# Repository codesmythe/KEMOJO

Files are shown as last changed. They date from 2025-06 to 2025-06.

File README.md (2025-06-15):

# KEMOJO (Keyboard / Mouse / Joystick)

KEMOJO

This board provides PS/2 keyboard, PS/2 mouse and Atari or MSX (single
button only) joystick support for an RCBus system. It uses the 40-pin
RCBus interface. 

The keyboard, mouse and joystick inputs are read by an ATmega 328P
microcontoller. (This is the same MCU that is in the Arduino UNO.) The
ATmega implements the [Atari ST IKBD
protcol](https://archive.org/details/Intelligent_Keyboard_ikbd_Protocol_Feb_26_1985/)
and communicates that protocol serially to an RCBus system via a
16C550 UART.

## Table of Contents
* [Hardware Documentation](#hardware-documentation)
  * [Schematic](#schematic)
  * [Connectors](#connectors)
  * [Jumpers](#jumpers)
  * [Bill of Materials](#bill-of-materials)
* [Firmware Documentation](#firmware-documentation)
* [Acknowledgements](#acknowledgements)

## Hardware Documentation

### Schematic

The board was created using [Kicad](https://www.kicad.org) version 8.0.

Click the image to download a PDF version of the schematic.

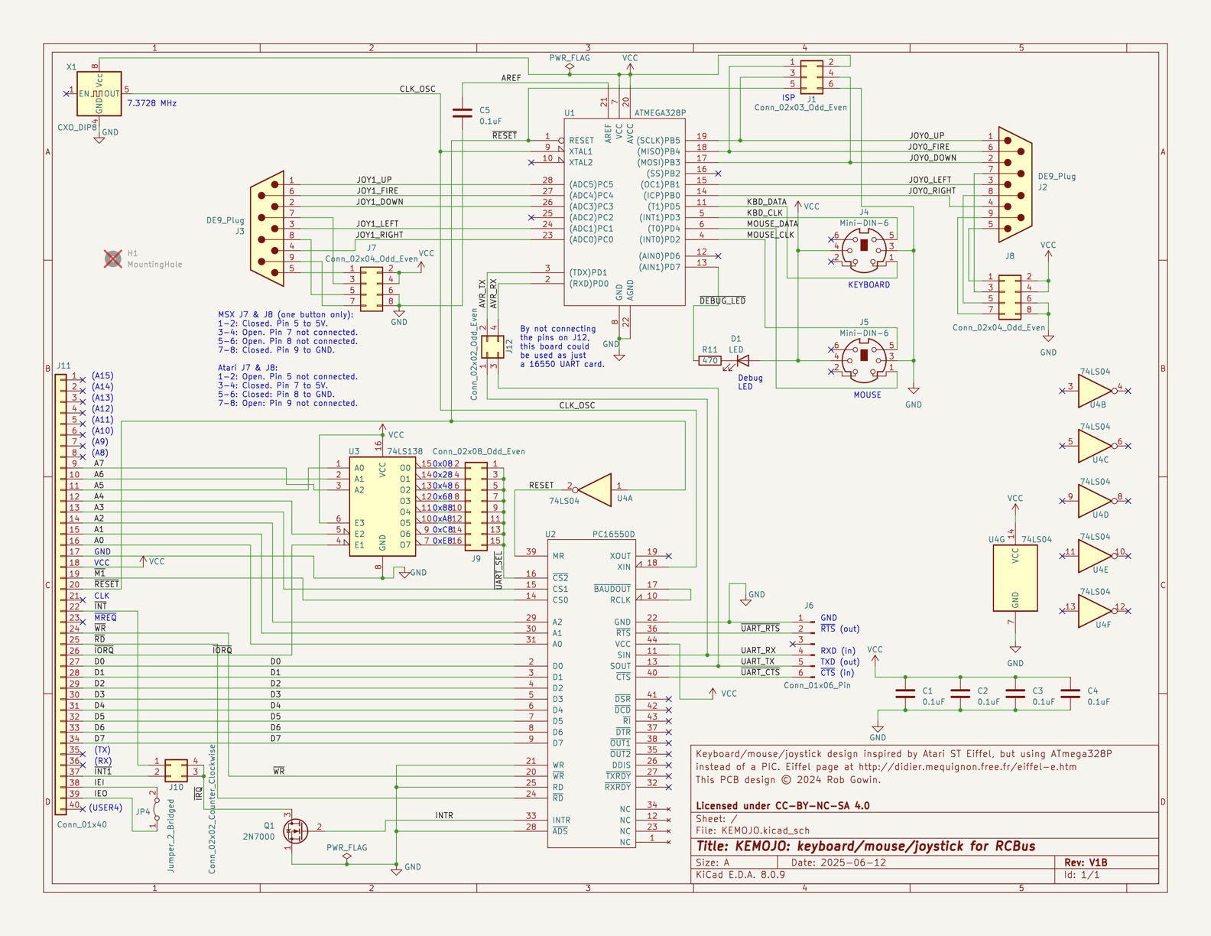
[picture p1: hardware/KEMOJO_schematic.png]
Schematic


### Connectors

| Reference | Description |
| --- | --- |
| J1 | In-system Programming (ISP) port for programming the ATmega328P firmware. |
| J2 | Atari or MSX Joystick 0, Male DE9 D-Sub. See J7 jumper settings below. |
| J3 | Atari or MSX Joystick 1, Male DE9 D-Sub. See J8 jumper settings below. |
| J4 | PS/2 6-pin Mini DIN connector for PS/2 keyboard. |
| J5 | PS/2 6-pin Mini DIN connector for PS/2 mouse. |
| J6 | [FTDI Friend](https://www.adafruit.com/product/284) connection to 16C550 UART. For debug purposes or UART-only operation. |

### Jumpers

| Reference | Description | Comment |
| --- | --- | --- |
| J7, J8 | Atari or MSX operation for Joystick 1/0 | The J7 and J8 jumper blocks configue Joystick 1 and Joystick 0, respectively, for either Atari or MSX joystick operation. In MSX mode, only one fire button is supported. To configure a jumper block for Atari mode, close the top and bottom jumpers, and leave the middle two open. For MSX mode, close the middle two jumpers and leave the top and bottom jumpers open. |
| J9 | I/O Address decode | The J9 jumper block controls where in the Z80 I/O space the KEMOJO board will appear. The TL16C550 UART that communicates with the ATmega328 requires eight I/O addresses, and can be configured to appear at I/O addresses 0x08-0x0F, 0x28-0x2F, 0x48-0x4F, 0x68-0x6F, 0x88-0x8F, 0xA8-0xAF, 0xC8-0xCF or 0xE8-0xEF. |
| J10 | Interrupt connection to RCBus | The board can generate a single interrupt from the TL16C550 UART. Jumper the top two pins of J10 to use the /INT RCBus signal (pin 22) or the bottom two pins to use the RCBus USER1/INT1 signal (pin 37). |
| JP4 | IEx bypass | When the JP4 jumper is closed, the RCBus-Z80 IEI signal (pin 37) is connected directly to the IEO signal (pin 38). When closed, the board is disconnected from RCBus pins 37 and 38. The KEMOJO board does not use IEI or IEO. This jumper is provided to propagate the IEI/IEO daisy chained if required by the system. |

### Bill of Materials

[Text file parts list](hardware/KEMOJO_mouser.txt) for pasting into the [Mouser BOM tool](https://www.mouser.com/Bom/CopyPaste) (login required).

Check out the [interactive BOM](https://htmlpreview.github.io/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)
for the board.

To obtain a KEMOJO PCB, download these [Gerbers](https://raw.githubusercontent.com/codesmythe/KEMOJO/refs/heads/main/hardware/KEMOJO_V1B.zip) for use at your preferred PCB manufacturer. I use JLCPCB. 

| Component Type | Reference | Qty | Description | Part |
| --- | --- | --- | --- | --- |
| Capacitor | C1,C2,C3,C4,C5 | 5 | 0.1 uF, MLCC, 5 mm Pitch | Mouser [594-K104K15X7RF5WH5](https://www.mouser.com/ProductDetail/594-K104K15X7RF5WH5) |
| Diode | D1 | 1 | 3 mm, yellow LED indicator | Mouser [859-LTL-4251N](https://www.mouser.com/ProductDetail/859-LTL-4251N) |
| Connnector | J1 | 1 | 2x3 straight pin header | Mouser [200-TSW10307TD](https://www.mouser.com/ProductDetail/200-TSW10307TD) |
| Connector | J2,J3 | 2 | D-Sub DE9 Male, right angle, PCB mount | Mouser [523-L7SDE9PA4CH4RC39](https://www.mouser.com/ProductDetail/523-L7SDE9PA4CH4RC39) |
| Connector | J4,J5 | 2 | Circular 6-pin Mini Din Connector for PS/2 | Mouser [490-MD-40SM](https://www.mouser.com/ProductDetail/490-MD-40SM) |
| Connector | J6 | 1 | 1x6 right angle pin header | Mouser [737-PH1RB-06-UA](https://www.mouser.com/ProductDetail/737-PH1RB-06-UA) |
| Jumper Block | J7,J8 | 2 | 2x4 straight pin header | Mouser [200-TSW10407TD](https://www.mouser.com/ProductDetail/200-TSW10407TD) |
| Jumper Block | J9 | 1 | 2x8 straight pin header | Mouser [200-TSW10807TD](https://www.mouser.com/ProductDetail/200-TSW10807TD) |
| Jumper Block | J10 | 1 | 2x2 straight pin header | Mouser [200-TSW10207TD](https://www.mouser.com/ProductDetail/200-TSW10207TD) |
| Connector | J11 | 1 | 1x40 right angle pin header | Mouser [710-61304011021](https://www.mouser.com/ProductDetail/710-61304011021) |
| Jumper Block | J12 | 1 | 2x2 straight pin header | Mouser [200-TSW10207TD](https://www.mouser.com/ProductDetail/200-TSW10207TD) |
| Jumper | JP4 | 1 | 1x2 straight pin header | Mouser [200-TSW10207TS](https://www.mouser.com/ProductDetail/200-TSW10207TS) |
| Transistor | Q1 | 1 | 2N7000  MOSFET in TO92 | Mouser [512-2N7000](https://www.mouser.com/ProductDetail/512-2N7000) |
| Resistor | R11 | 1 | 470 ohm, axial, 1% tolerance, 1/4 W | Mouser [603-MFR-25FTF52-470R](https://www.mouser.com/ProductDetail/603-MFR-25FTF52-470R) |
| Integrated Circuit | U1 | 1 | ATmega328P MCU in 28-pin DIP | Mouser [556-ATMEGA328P-PU](https://www.mouser.com/ProductDetail/556-ATMEGA328P-PU) |
| Integrated Circuit | U2 | 1 | TL16C550 UART in 44-pin PLCC | Mouser [595-TL16C550CFNR](https://www.mouser.com/ProductDetail/595-TL16C550CFNR) |
| Integrated Circuit | U3 | 1 | 74LS138 in 16-pin DIP | Mouser [595-SN74LS138NE4](https://www.mouser.com/ProductDetail/595-SN74LS138NE4) |
| Integrated Circuit | U4 | 1 | 74LS04 in 14-pin DIP | Mouser [595-SN74LS04NE4](https://www.mouser.com/ProductDetail/595-SN74LS04NE4) |
| Oscillator | X1 | 1 | 7.3278 MHz can oscillator in 8-pin DIP | Mouser [774-MXO45HS-3C-7.3](https://www.mouser.com/ProductDetail/774-MXO45HS-3C-7.3) |
| Socket | Socket for U1  | 1 | 28-pin DIP socket | Mouser [737-ICS-328-T](https://www.mouser.com/ProductDetail/737-ICS-328-T) |
| Socket | Socket for U2  | 1 | 44-pin PLCC socket | Mouser [575-944424](https://www.mouser.com/ProductDetail/575-944424) |
| Socket | Socket for U3  | 1 | 16-pin DIP socket | Mouser [571-1-2199298-4](https://www.mouser.com/ProductDetail/571-1-2199298-4) |
| Socket | Socket for U4  | 1 | 14-pin DIP socket | Mouser [571-1-2199298-3](https://www.mouser.com/ProductDetail/571-1-2199298-3) |
| Socket | Socket for X1  | 1 | 8-pin oscillator socket | Mouser [535-1108800](https://www.mouser.com/ProductDetail/535-1108800) |

## Acknowledgements

This project has initially inspired by the [Atari ST Eiffel 3](http://didier.mequignon.free.fr/eiffel-e.htm)
project. I've replaced the PIC microcontroller in that project with
an easier-to-use ATmega 328P.

The low-level PS/2 code watches the PS/2 keyboard and mouse clock
lines for transitions and signals an interrupt the ATmega. This code
then reads in PS/2 bytes and buffers them. It was written by Daniel
Cliche (@danodus) and is made available by him under an MIT license
from [here](https://github.com/danodus/rosco_m68k_io).

The higher level code that implements the Atari ST IKDB protocol is
borrowed from the [Hatari](https://www.hatari-emu.org) Atari ST
emulator. It is made available under the GNU GPL, version 2 or higher. 

The overall project thus uses the GNU GPL, version 2 or higher.

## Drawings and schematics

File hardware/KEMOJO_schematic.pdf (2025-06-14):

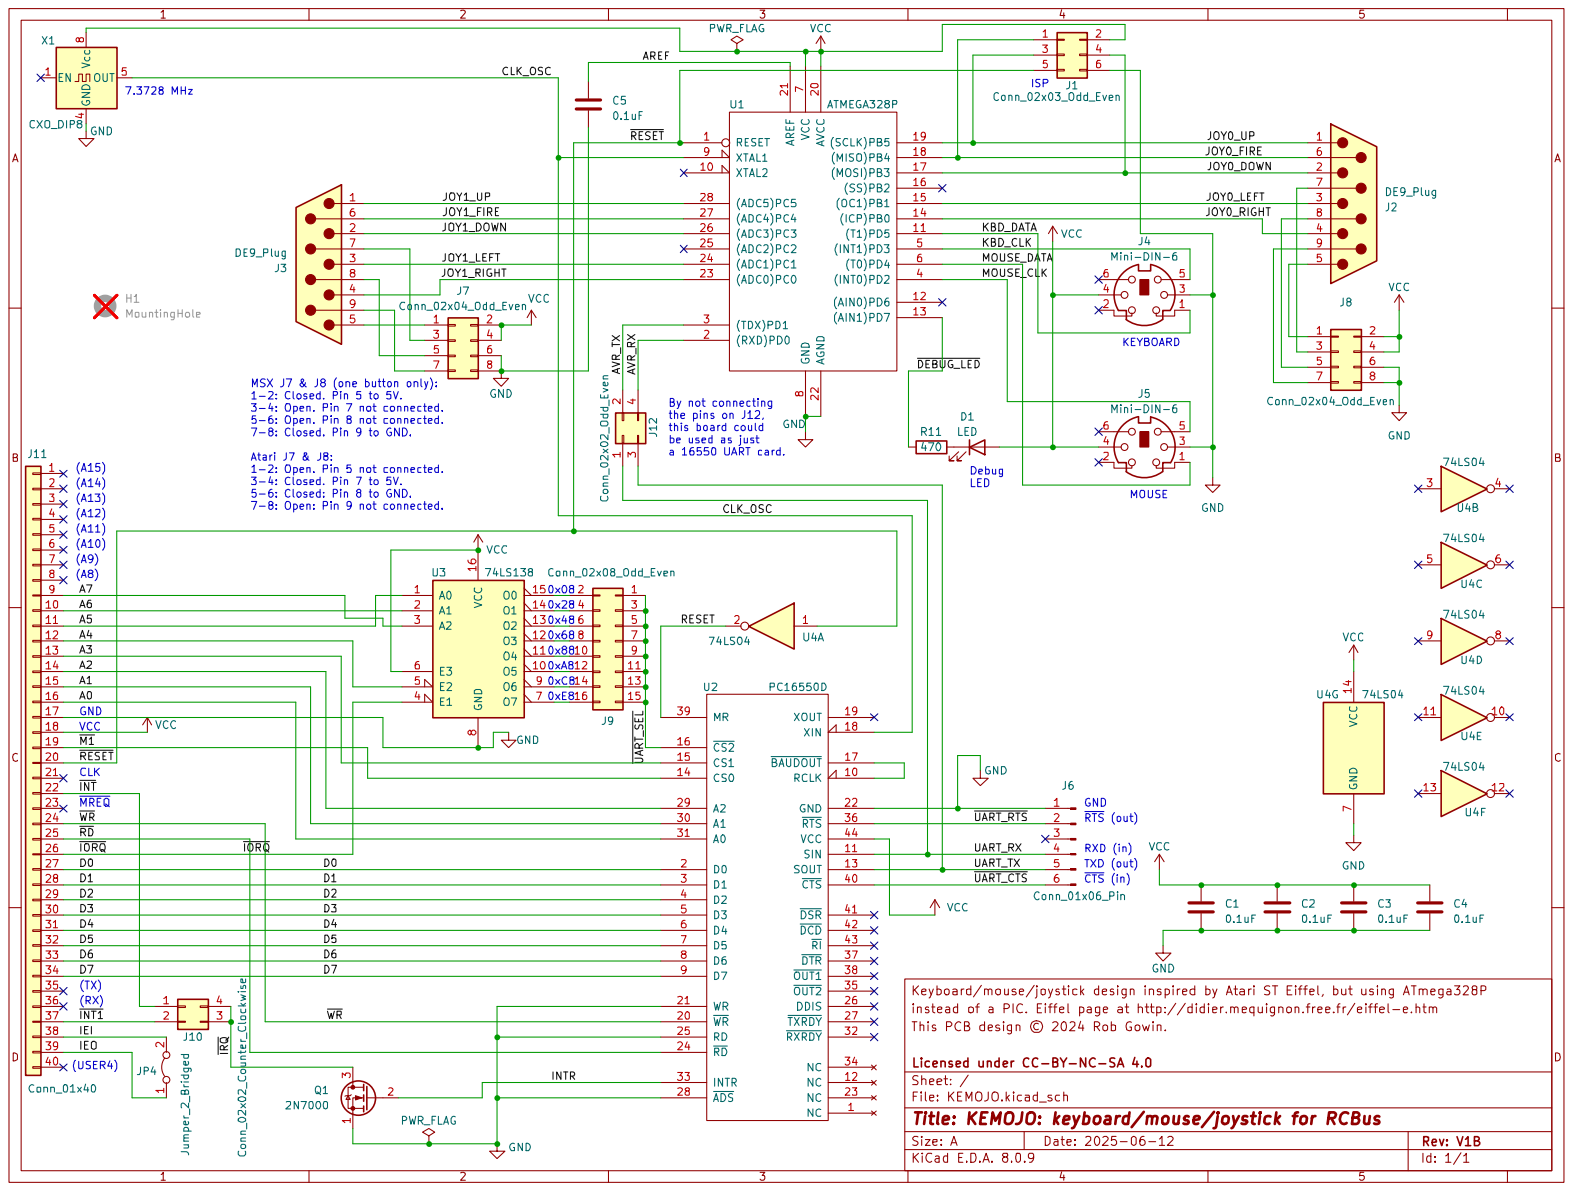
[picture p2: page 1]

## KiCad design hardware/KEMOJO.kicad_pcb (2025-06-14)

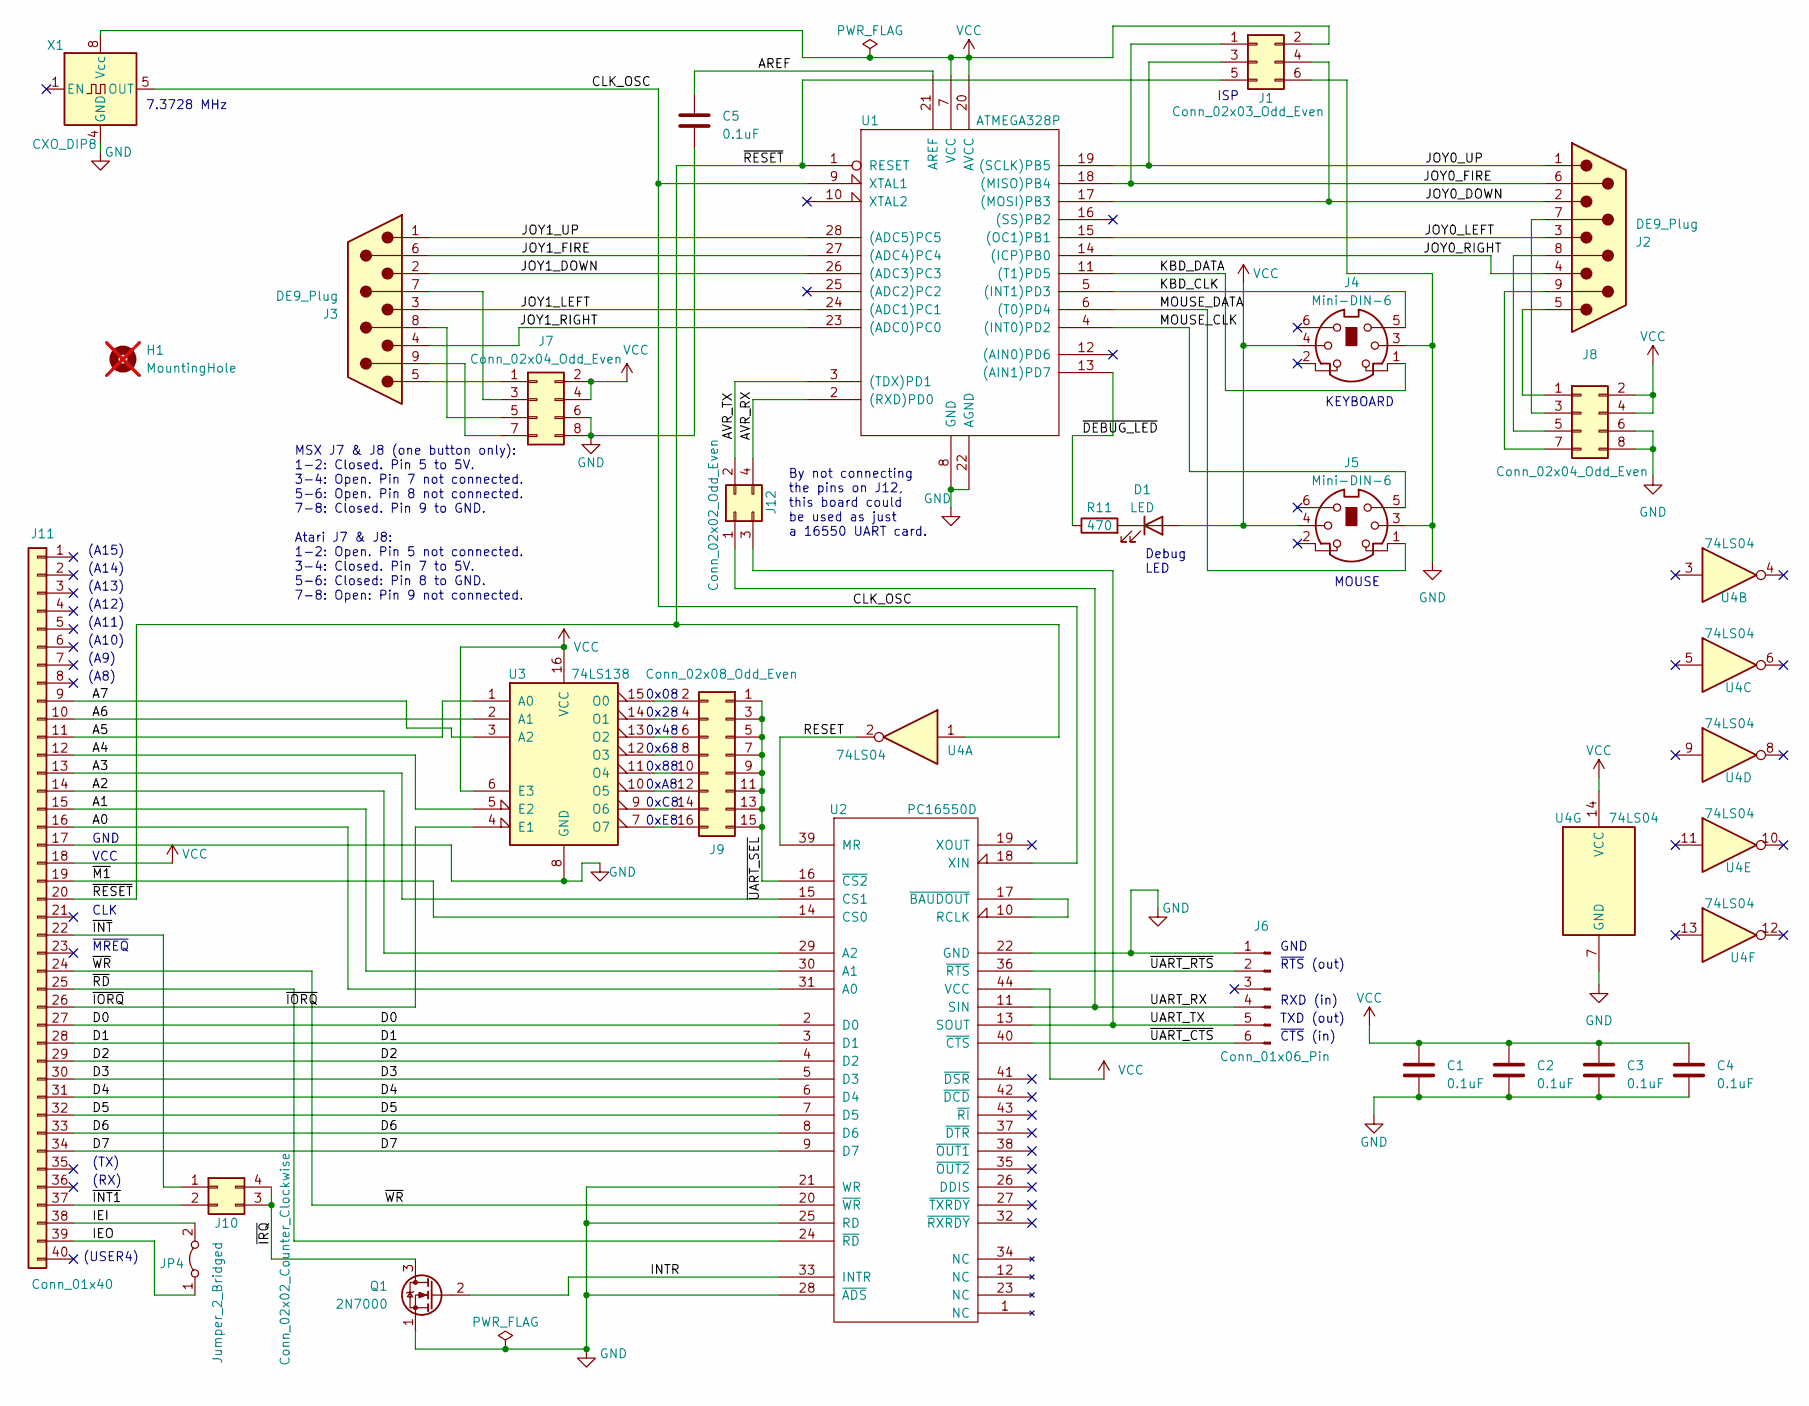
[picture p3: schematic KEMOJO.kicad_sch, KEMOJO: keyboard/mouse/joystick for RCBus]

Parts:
C1, C2, C3, C4, C5: 0.1uF; C_Rect_L7.0mm_W2.0mm_P5.00mm; PartNum00 594-K104K15X7RF5WH5
D1: LED; LED_D3.0mm; PartNum00 859-LTL-4251N
H1: MountingHole; MountingHole_3.2mm_M3; not fitted
J1: Conn_02x03_Odd_Even; PinHeader_2x03_P2.54mm_Vertical; PartNum00 200-TSW10307TD
J2, J3: DE9_Plug; DSUB-9_Male_Horizontal_P2.77x2.84mm_EdgePinOffset4.94mm_Hou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; PartNum00 523-L7SDE9PA4CH4RC39
J4, J5: Mini-DIN-6; mini_din; PartNum00 490-MD-40SM
J6: Conn_01x06_Pin; PinHeader_1x06_P2.54mm_Vertical; PartNum00 737-PH1RB-06-UA
J7, J8: Conn_02x04_Odd_Even; PinHeader_2x04_P2.54mm_Vertical; PartNum00 200-TSW10407TD
J9: Conn_02x08_Odd_Even; PinHeader_2x08_P2.54mm_Vertical; PartNum00 200-TSW10807TD
J10: Conn_02x02_Counter_Clockwise; PinHeader_2x02_P2.54mm_Vertical; PartNum00 200-TSW10207TD
J11: Conn_01x40; PinHeader_1x40_P2.54mm_Vertical; PartNum00 710-61304011021
J12: Conn_02x02_Odd_Even; PinHeader_2x02_P2.54mm_Vertical; PartNum00 200-TSW10207TD
JP4: Jumper_2_Bridged; PinHeader_1x02_P2.54mm_Vertical; PartNum00 200-TSW10207TS
Q1: 2N7000; TO-92_HandSolder; PartNum00 512-2N7000
R11: 470; R_Axial_DIN0207_L6.3mm_D2.5mm_P7.62mm_Horizontal; PartNum00 603-MFR-25FTF52-470R
U1: ATMEGA328P; DIP-28_W7.62mm_Socket_LongPads; PartNum00 556-ATMEGA328P-PU
U2: PC16550D; PLCC-44_THT-Socket; PartNum00 595-TL16C550CFNR
U3: 74LS138; DIP-16_W7.62mm_Socket_LongPads; PartNum00 595-SN74LS138NE4
U4: 74LS04; DIP-14_W7.62mm_Socket_LongPads; PartNum00 595-SN74LS04NE4
X1: CXO_DIP8; Oscillator_DIP-8; PartNum00 774-MXO45HS-3C-7.3

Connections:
/A0: J11.16, U2.31 (A0)
/A1: J11.15, U2.30 (A1)
/A2: J11.14, U2.29 (A2)
/A3: J11.13, U2.15 (CS1)
/A4: J11.12, U3.5 (E2)
/A5: J11.11, U3.1 (A0)
/A6: J11.10, U3.2 (A1)
/A7: J11.9, U3.3 (A2)
/AREF: C5.2, U1.21 (AREF)
/AVR_RX: J12.4, U1.2 ((RXD)PD0)
/AVR_TX: J12.2, U1.3 ((TDX)PD1)
/CLK_OSC: U1.9 (XTAL1), U2.18 (XIN), X1.5 (OUT)
/D0: J11.27, U2.2 (D0)
/D1: J11.28, U2.3 (D1)
/D2: J11.29, U2.4 (D2)
/D3: J11.30, U2.5 (D3)
/D4: J11.31, U2.6 (D4)
/D5: J11.32, U2.7 (D5)
/D6: J11.33, U2.8 (D6)
/D7: J11.34, U2.9 (D7)
/IEI: J11.38, JP4.2 (B)
/IEO: J11.39, JP4.1 (A)
/INTR: Q1.2 (G), U2.33 (INTR)
/JOY0_DOWN: J1.4, J2.2, U1.17 ((MOSI)PB3)
/JOY0_FIRE: J1.1, J2.6, U1.18 ((MISO)PB4)
/JOY0_LEFT: J2.3, U1.15 ((OC1)PB1)
/JOY0_RIGHT: J2.4, U1.14 ((ICP)PB0)
/JOY0_UP: J1.3, J2.1, U1.19 ((SCLK)PB5)
/JOY1_DOWN: J3.2, U1.26 ((ADC3)PC3)
/JOY1_FIRE: J3.6, U1.27 ((ADC4)PC4)
/JOY1_LEFT: J3.3, U1.24 ((ADC1)PC1)
/JOY1_RIGHT: J3.4, U1.23 ((ADC0)PC0)
/JOY1_UP: J3.1, U1.28 ((ADC5)PC5)
/KBD_CLK: J4.5, U1.5 ((INT1)PD3)
/KBD_DATA: J4.1, U1.11 ((T1)PD5)
/MOUSE_CLK: J5.5, U1.4 ((INT0)PD2)
/MOUSE_DATA: J5.1, U1.6 ((T0)PD4)
/RESET: U2.39 (MR), U4.2
/UART_RX: J6.4, J12.1, U2.11 (SIN)
/UART_TX: J6.5, J12.3, U2.13 (SOUT)
/~DEBUG_LED: R11.1, U1.13 ((AIN1)PD7)
/~INT1: J10.2, J11.37
/~INT: J10.1, J11.22
/~IORQ: J11.26, U3.4 (E1)
/~IRQ: J10.3, J10.4, Q1.3 (D)
/~M1: J11.19, U2.14 (CS0)
/~RD: J11.25, U2.24 (~RD)
/~RESET: J1.5, J11.20, U1.1 (RESET), U4.1
/~UART_CTS: J6.6, U2.40 (~CTS)
/~UART_RTS: J6.2, U2.36 (~RTS)
/~UART_SEL: J9.1, J9.3, J9.5, J9.7, J9.9, J9.11, J9.13, J9.15, U2.16 (~CS2)
/~WR: J11.24, U2.20 (~WR)
GND: C1.1, C2.1, C3.1, C4.1, C5.1, J1.6, J4.3, J5.3, J6.1, J7.6, J7.8, J8.6, J8.8, J11.17, Q1.1 (S), U1.8 (GND), U1.22 (AGND), U2.21 (WR), U2.22 (GND), U2.25 (RD), U2.28 (~ADS), U3.8 (GND), U4.7 (GND), X1.4 (GND)
unnamed: D1.1 (K), R11.2
unnamed: J3.5, J7.1
unnamed: J3.7, J7.3
unnamed: J3.8, J7.5
unnamed: J3.9, J7.7
unnamed: J2.5, J8.1
unnamed: J2.7, J8.3
unnamed: J2.8, J8.5
unnamed: J2.9, J8.7
unnamed: J9.2, U3.15 (O0)
unnamed: J9.4, U3.14 (O1)
unnamed: J9.6, U3.13 (O2)
unnamed: J9.8, U3.12 (O3)
unnamed: J9.10, U3.11 (O4)
unnamed: J9.12, U3.10 (O5)
unnamed: J9.14, U3.9 (O6)
unnamed: J9.16, U3.7 (O7)
unnamed: U2.10 (RCLK), U2.17 (~BAUDOUT)
VCC: C1.2, C2.2, C3.2, C4.2, D1.2 (A), J1.2, J4.4, J5.4, J7.2, J7.4, J8.2, J8.4, J11.18, U1.7 (VCC), U1.20 (AVCC), U2.44 (VCC), U3.6 (E3), U3.16 (VCC), U4.14 (VCC), X1.8 (Vcc)

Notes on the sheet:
0x48
ISP
RXD (in)
(RX)
By not connecting the pins on J12, this board could be used as just a 16550 UART card.
(A11)
0x68
GND
KEYBOARD
0x28
(A8)
MSX J7 & J8 (one button only): 1-2: Closed. Pin 5 to 5V. 3-4: Open. Pin 7 not connected. 5-6: Open. Pin 8 not connected. 7-8: Closed. Pin 9 to GND. Atari J7 & J8: 1-2: Open. Pin 5 not connected. 3-4: Closed. Pin 7 to 5V. 5-6: Closed: Pin 8 to GND. 7-8: Open: Pin 9 not connected.
~{CTS} (in)
(TX)
0x08
(USER4)
(A15)
~{MREQ}
~{RTS} (out)
0xC8
7.3728 MHz
CLK
TXD (out)
(A12)
0x88
(A14)
(A9)
0xA8
VCC
(A13)
0xE8
(A10)
Debug LED
MOUSE

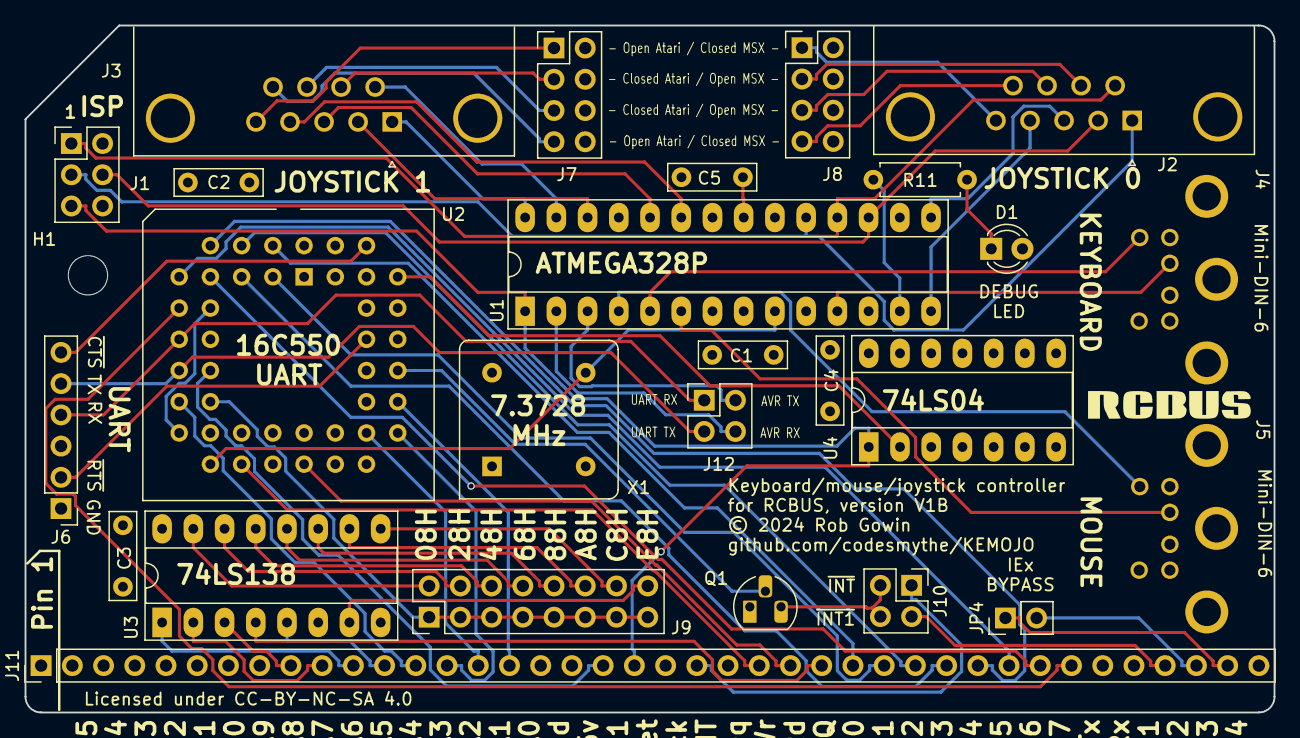
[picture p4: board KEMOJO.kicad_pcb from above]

Board: 4 copper layers, 101.6 x 55.9 mm, 27 parts (0 on the bottom side), 72 nets.

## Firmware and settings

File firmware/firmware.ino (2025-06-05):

// kemojo_firmware.cpp
// Copyright (c) 2025 Rob Gowin
// Copyright (c) 2023-2024 Daniel Cliche
// SPDX-License-Identifier: MIT

#include "ps2_keyboard.h"
#include "ps2_mouse.h"

#include "config.h"
#include "ikbd.h"
#include "ps2.h"
#include "util.h"

PS2Keyboard keyboard;
PS2Mouse mouse;
KEYBOARD Keyboard;
KEYBOARD_PROCESSOR KeyboardProcessor;

#include <Arduino.h>

#include "scan_code_maps_flash.c"

PROGMEM constexpr char key_press_msg[] = "    Key pressed: ";
PROGMEM constexpr char key_release_msg[] = "    Key released: ";
PROGMEM constexpr char scan_code_msg[] = "Scan code: 0x";
PROGMEM constexpr char st_scan_code_msg[] = "    Atari ST Scan Code: 0x";

void setup()
{
  // Configure the debug LED pin as output
  pinMode(PIN7, OUTPUT);
  Serial.begin(SERIAL_BAUD_RATE);

  // Set up the joystick ports by setting bits 5:0 of ports B and C to inputs.
  DDRB = DDRB & 0xC0;
  DDRC = DDRC & 0xC0;
  // And pull them up.
  PORTB = PORTB | 0x3F;
  PORTC = PORTC | 0x3F;

#if KEYBOARD_ENA
    PS2Keyboard::begin(PS2_KEYBOARD_CLK_PIN, PS2_KEYBOARD_DATA_PIN);
#endif
#if MOUSE_ENA
    PS2Mouse::begin(PS2_MOUSE_CLK_PIN, PS2_MOUSE_DATA_PIN);
#endif
    IKBD_Reset(true);
}

void turn_LED_on()
{
  digitalWrite(PIN7, 0);
}

void turn_LED_off()
{
  digitalWrite(PIN7, 1);
}

void check_ikbd_output_buffer()
{
  if ( Keyboard.NbBytesInOutputBuffer > 0 && Keyboard.PauseOutput == false ) {
    const unsigned char ch = Keyboard.Buffer[ Keyboard.BufferHead++ ];
    Keyboard.BufferHead &= KEYBOARD_BUFFER_MASK;
    Keyboard.NbBytesInOutputBuffer--;
    send_byte(ch);
  }
}

#define Y_OVERFLOW (1 << 7)
#define X_OVERFLOW (1 << 6)
#define Y_SIGN (1 << 5)
#define X_SIGN (1 << 4)
#define MIDDLE_BUTTON (1 << 2)
#define RIGHT_BUTTON (1 << 1)
#define LEFT_BUTTON (1 << 0)

#if DEBUG

static void print_hex_byte(uint8_t value) {
  uint8_t upper = (value >> 4) & 0xF, lower = value & 0xF;
  Serial.write(upper < 10 ? upper + '0' : upper + 'A' - 10);
  Serial.write(lower < 10 ? lower + '0' : lower + 'A' - 10);
}

static void show_scan_code(uint8_t code)
{
  Serial.print(reinterpret_cast<const __FlashStringHelper *>(scan_code_msg));
  print_hex_byte(code);
  Serial.println("");
}

static void show_st_scan_code(uint8_t code)
{
  Serial.print(reinterpret_cast<const __FlashStringHelper *>(st_scan_code_msg));
  print_hex_byte(code);
  Serial.println("");
}

static void show_key(uint8_t code, uint8_t extended, uint8_t brk)
{
  char key[20];
  if (extended) strcpy_P(key, reinterpret_cast<const char *>(pgm_read_word(&extended_ps2_make_code_map_flash[code])));
  else strcpy_P(key, reinterpret_cast<const char *>(pgm_read_word(&ps2_make_code_map_flash[code])));
  if (brk) Serial.print(reinterpret_cast<const __FlashStringHelper *>(key_release_msg));
  else Serial.print(reinterpret_cast<const __FlashStringHelper *>(key_press_msg));

  Serial.print(key);
  Serial.print("   --->   ");
}

#endif

extern "C" {
  uint8_t Joy_GetStickData(const int nStJoyId)
  {
    // FIXME: Deal with joystick emulation and autofire. See full function in Hatari src/joy.c.
    uint8_t result = 0;
    // Get the value of the GPIO port
    uint8_t gpio_value = (nStJoyId == 0 ? PINB : PINC) & 0x3F;

    // Arrange the bits in the order expected by the IKBD protocol.
    if (!(gpio_value & GPIO_MASK_UP))    result |= ATARIJOY_BITMASK_UP;
    if (!(gpio_value & GPIO_MASK_DOWN))  result |= ATARIJOY_BITMASK_DOWN;
    if (!(gpio_value & GPIO_MASK_LEFT))  result |= ATARIJOY_BITMASK_LEFT;
    if (!(gpio_value & GPIO_MASK_RIGHT)) result |= ATARIJOY_BITMASK_RIGHT;
    if (!(gpio_value & GPIO_MASK_FIRE))  result |= ATARIJOY_BITMASK_FIRE;

    return result;
  }
}

#if KEYBOARD_ENA


void poll_keyboard()
{
  bool avail = false, buffer_overflow = false, leave_led_on = false;
  static bool brk = false, extended = false, caps_lock_led = false;
  const uint8_t code = PS2Keyboard::read(&avail, &buffer_overflow);
  if (buffer_overflow) leave_led_on = true;
  if (avail) {
#if DEBUG
    show_scan_code(code);
#endif
    turn_LED_on();
    if (code == 0xF0) brk = true;
    else if (code == 0xE0) extended = true;
    else if (code == 0xE1) { // Pause/Break handing
      // E1 14 77 E1 F0 14 F0 77
      // Eat the next seven bytes
      int remaining = 7;

      while (remaining) {
        do {
          PS2Keyboard::read(&avail, &buffer_overflow);
        } while (!avail);
        remaining--;
      }
      // This key press/release is completely ignored.
    } else if (code != 0xAA) {
      uint8_t st_scan_code = pgm_read_byte(&st_make_code_map[code]);
      if (extended) st_scan_code = pgm_read_byte(&st_extended_make_code_map[code]);
      IKBD_PressSTKey(st_scan_code, !brk);
      if (code == 0x58 && !brk) { // caps lock
        caps_lock_led = !caps_lock_led;
        PS2Keyboard::set_caps_lock_led(caps_lock_led);
      }
      brk = false;
      extended = false;
    }
    if (!leave_led_on) turn_LED_off();
  }
}
#endif

void poll_mouse()
{
  bool avail = false, buffer_overflow = false, leave_led_on = false;
  const uint8_t mstat = PS2Mouse::read(&avail, &buffer_overflow);
  if (buffer_overflow) leave_led_on = true;
  if (avail) {
    turn_LED_on();
    uint8_t dx8 = 0, dy8 = 0;
    do {
      dx8 = PS2Mouse::read(&avail, &buffer_overflow);
      if (buffer_overflow) leave_led_on = true;
    } while (!avail); // Keep attempting to read a byte while nothing available in the buffer.
    do {
      dy8 = PS2Mouse::read(&avail, &buffer_overflow);
      if (buffer_overflow) leave_led_on = true;
    } while (!avail);
    unsigned int dx = dx8, dy = dy8;
    if (mstat & X_SIGN) dx = 0xFF00 | dx8; /* sign extend */
    if (mstat & Y_SIGN) dy = 0xFF00 | dy8;
    KeyboardProcessor.Mouse.dx += (int) dx;
    KeyboardProcessor.Mouse.dy += (int) dy;

    if (mstat & RIGHT_BUTTON) Keyboard.bRButtonDown |= BUTTON_MOUSE;
    else Keyboard.bRButtonDown &= ~BUTTON_MOUSE;

    if (mstat & LEFT_BUTTON) Keyboard.bLButtonDown |= BUTTON_MOUSE;
    else Keyboard.bLButtonDown &= ~BUTTON_MOUSE;

    /* FIXME: Deal with mouse overflow bits. */
    if (!leave_led_on) turn_LED_off();
  }
}

void loop() {
  bool avail = false;
  // See if there is an incoming command byte.
  const unsigned char c = recv_byte(&avail);
  if (avail) IKBD_RunKeyboardCommand(c);
  // Next, we will check if there is keyboard or mouse activity.
  poll_mouse();
#if KEYBOARD_ENA
  poll_keyboard();
#endif
  // See if the IKBD has any response.
  IKBD_SendAutoKeyboardCommands();
  check_ikbd_output_buffer();
}

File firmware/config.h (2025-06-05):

// config.h
// Copyright (c) 2023-2024 Daniel Cliche
// SPDX-License-Identifier: MIT

#ifndef __CONFIG_H__
#define __CONFIG_H__

// Serial port
#define SERIAL_BAUD_RATE 9600

#define KEYBOARD_ENA 1
#define MOUSE_ENA 1

// Pinout
#define PS2_MOUSE_CLK_PIN 2      // ATMEGA PIN 4
#define PS2_KEYBOARD_CLK_PIN 3   // ATMEGA PIN 5
#define PS2_MOUSE_DATA_PIN 4     // ATMEGA PIN 6
#define PS2_KEYBOARD_DATA_PIN 5  // ATMEGA PIN 11

#define PS2_TIMEOUT 2000

#define DEBUG 0

#endif

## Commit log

2025-06-05 Initial commit.
    [KEMOJO.kicad_pcb, KEMOJO.kicad_sch]
2025-06-14 Add more documentation.
    [KEMOJO.kicad_pcb, KEMOJO.kicad_sch]
2025-06-15 Add Gerbers and interactive BOM.
2025-06-15 Fix Mouser BOM tool link.
2025-06-15 Tweak BOM listing.

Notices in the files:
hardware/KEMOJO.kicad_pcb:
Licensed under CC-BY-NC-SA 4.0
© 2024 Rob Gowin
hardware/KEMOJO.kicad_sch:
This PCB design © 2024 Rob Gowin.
